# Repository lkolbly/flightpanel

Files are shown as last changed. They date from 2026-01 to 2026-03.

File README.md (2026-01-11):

DIY Flightpanel
===============

Welcome to my DIY flightpanel. There are three components to this project:

* Mechanical design
* PCB design
* Firmware

All three are custom-built for this project.

PCB
===

The PCB has support for up to the following inputs:

* 16x push buttons
* 14x double-throw switches
* 6x rotary encoders with push-buttons
* 10x potentiometers or hall-effect sensors

(note that Windows only supports up to 8 axes)

Mechanical
==========

The mechanical design is in FreeCAD, in the `flightpanel.FCStd` file. Within
that project look at the Assembly for a reference design with all included
components, including stand-ins for various knobs and switches.

The design is oriented around providing a standardized base, with swappable
control scheme panels. Each panel has a working area of 60mm wide by 100mm tall
- see BigPanelTemplate in the FreeCAD project for a template. Two panels may be
combined to create a "wide" 128mm by 100mm panel.

The panel should extend 3.5mm past the centers of the holes for optimum
mechanical support.

The core structure provides space for up to 6 panels - two on the front face,
two on the top face (with an approximately 30 degree slope), and one on each
side.

The core consists of the following parts:
- `StructureFront`
- `StructureTop`
- `StructureBase`
- `SidePanel`

The mounting on the back is two M6 holes spaced 40mm apart vertically. Mouse bites are provided for additional rigidity. The `Mount` part provides a reference design for a mount - as modelled, for mounting to a 35mm wide square tube.

Hardware required for assembly:
- Heat-set M3 threaded inserts, designed for a 4.5mm diameter hole with 5mm depth.
- 14 to 38x M3 by 8mm bolts (14 for structure assembly, up to 24 for mounting panels).
- 2x M6 by 20mm bolts with nuts.

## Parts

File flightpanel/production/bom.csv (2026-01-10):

Designator | Footprint | Quantity | Value | LCSC Part #
C1, C10, C12, C2, C20, C22, C27, C28, C29, C4, C6, C8 | 0603 | 12 | 0.01uF | C57112
C11, C14, C16, C9 | 0603 | 4 | 4.7uF | C19666
C13, C18, C23, C24, C25, C3, C5, C7 | 0603 | 8 | 0.1uF | C14663
D1, D2 | 0603 | 2 | LED | C2286
J1 | USB-B-TH_USB-B10-BRW | 1 | USB_B | C720549
J10, J9 | PinHeader_1x04_P2.54mm_Vertical | 2 | Conn_01x04
J11, J7, J8 | PinHeader_1x03_P2.54mm_Vertical | 3 | Conn_01x03_Pin
J12 | PinHeader_2x05_P1.27mm_Vertical | 1 | Conn_ARM_JTAG_SWD_10 | C239059
J13 | PinHeader_1x03_P2.54mm_Vertical | 1 | Conn_01x03_Pin | C146690
J14, J2, J3, J4, J5, J6 | PinSocket_1x05_P2.54mm_Vertical | 6 | Conn_01x05 | C50950
R1, R10, R11, R12, R13, R14, R15, R16, R17, R18, R19, R2, R20, R3, R4, R43, R46, R49, R5, R50, R51, R52, R6, R7, R8, R9 | 0603 | 26 | 10k | C25804
R21, R22, R41, R42 | 0603 | 4 | 3k | C4211
R44, R45 | 0603 | 2 | 1k | C21190
R47, R48 | 0603 | 2 | 100k | C25803
RV1, RV2, RV3, RV4, RV5, RV6, RV7, RV8 | PinSocket_1x03_P2.54mm_Vertical | 8 | 10k | C146690
SW1, SW10, SW11, SW12, SW13, SW14, SW15, SW16, SW2, SW27, SW28, SW29, SW3, SW4, SW5, SW6, SW7, SW8, SW9 | PinSocket_1x02_P2.54mm_Vertical | 19 | SW_Push | C49661
SW17, SW18, SW19, SW20, SW21, SW22, SW23, SW32, SW33, SW34, SW35, SW36, SW37, SW38 | PinSocket_1x03_P2.54mm_Vertical | 14 | SW_SPDT | C146690
SW24 | SW-SMD_L3.9-W3.0-P4.45 | 1 | NRST | C720477
SW25 | SW-SMD_L3.9-W3.0-P4.45 | 1 | CFG | C720477
SW26 | SW-SMD_L3.9-W3.0-P4.45 | 1 | BOOT | C720477
TP1, TP2, TP3, TP4, TP5, TP6, TP7 | TestPoint_Pad_D2.0mm | 7 | TestPoint
U1, U2, U5, U7 | WQFN-24-1EP_4x4mm_P0.5mm_EP2.45x2.45mm | 4 | TCA9555RTWR | C140277
U3 | LQFP-48_7x7mm_P0.5mm | 1 | STM32F072CBTx | C81720
U6 | SOT-23-5 | 1 | TPS76333 | C7100

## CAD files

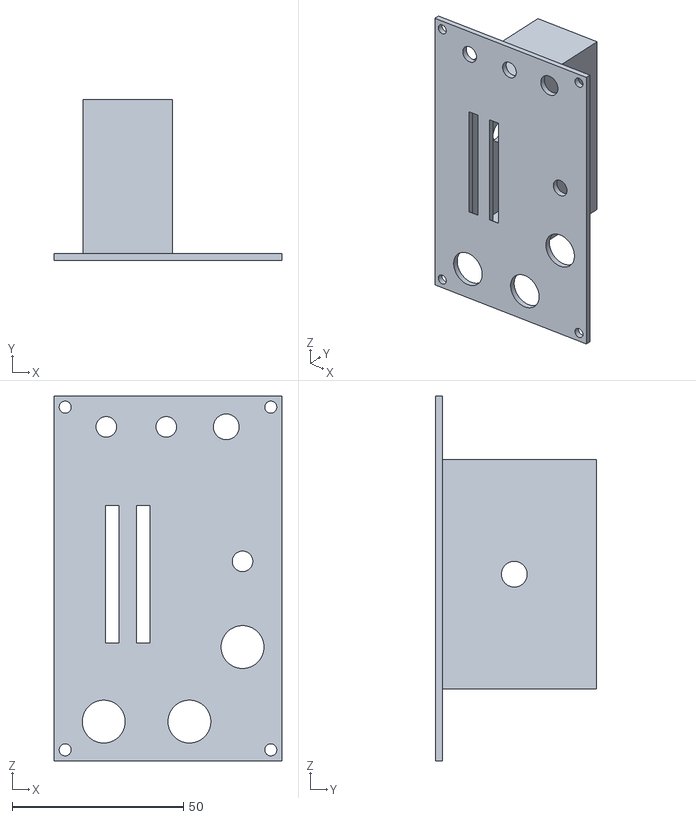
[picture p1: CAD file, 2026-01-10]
manufacturing/flightpanel-AssemblyFrontPlateModule001.stl
66.5 x 47.0 x 106.5

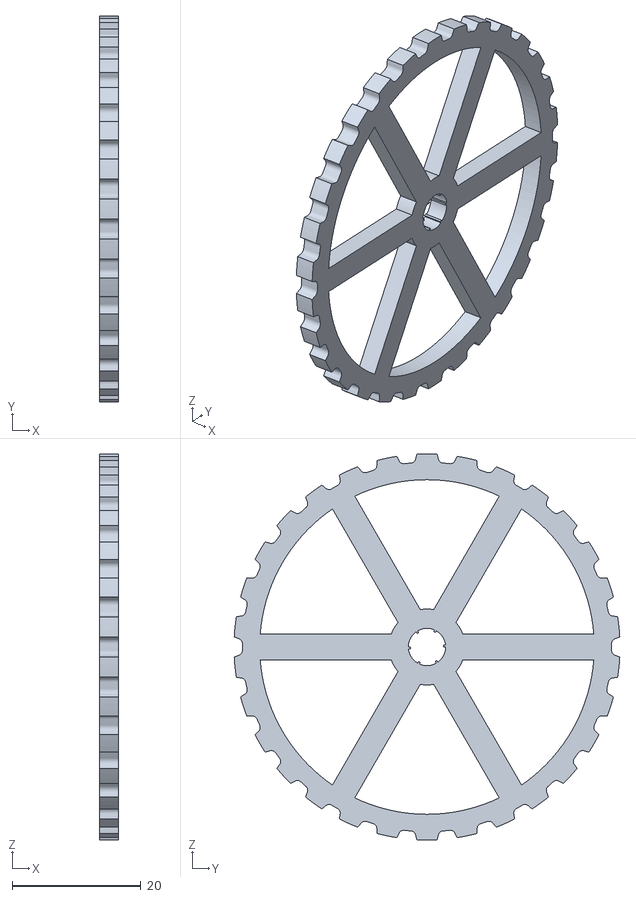
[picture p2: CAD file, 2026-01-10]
manufacturing/flightpanel-AssemblyWheel001.stl
3.00 x 59.9 x 60.0

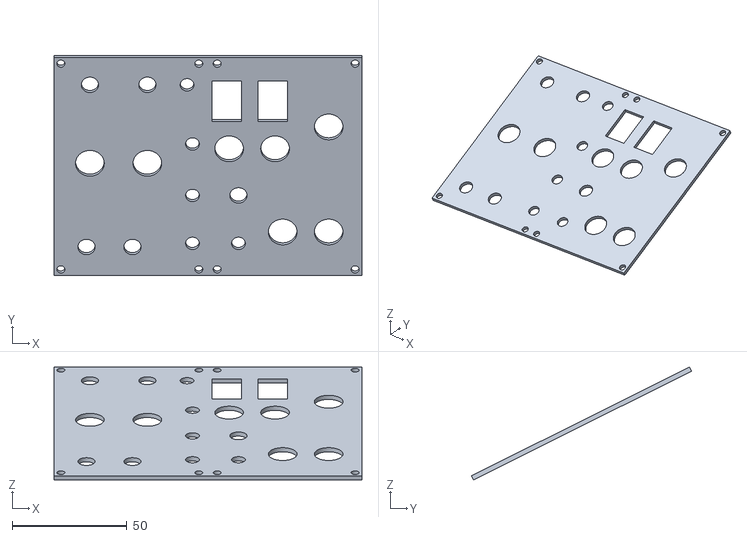
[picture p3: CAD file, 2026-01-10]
manufacturing/flightpanel-AssemblyBigTopPlateModule001.stl
134.0 x 95.8 x 49.1

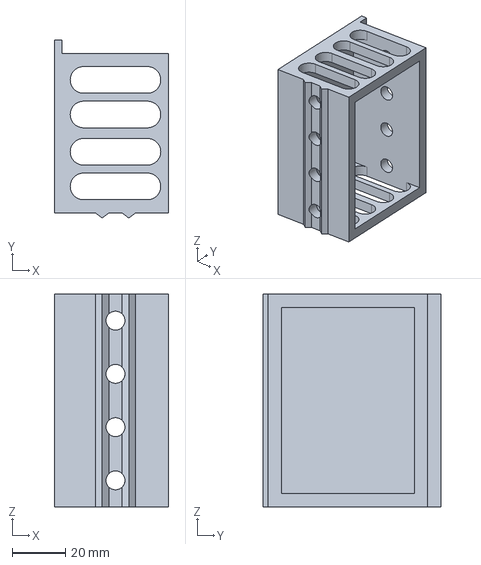
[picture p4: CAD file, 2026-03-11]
flightpanel.FCStd
43.0 x 66.9 x 80.0 mm

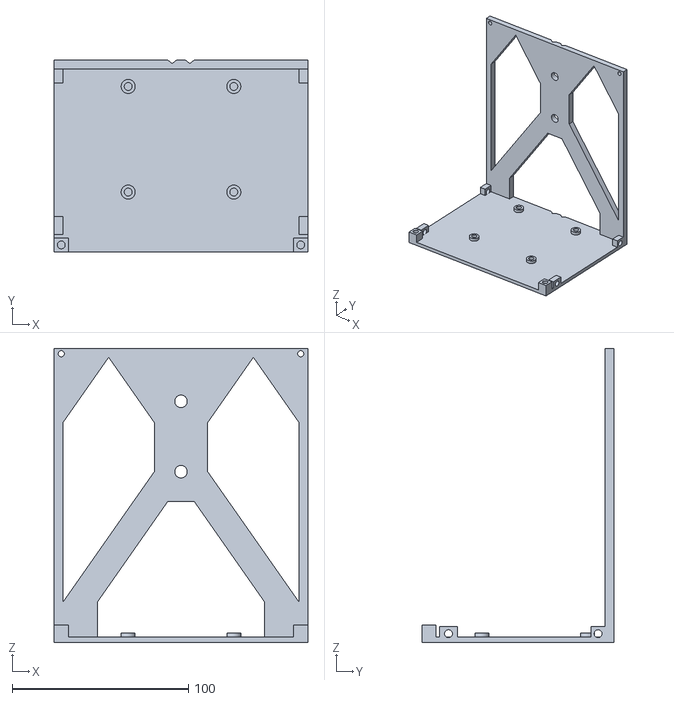
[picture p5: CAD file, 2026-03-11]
manufacturing/flightpanel-PartStructureBase.stl
144.0 x 109.0 x 167.0

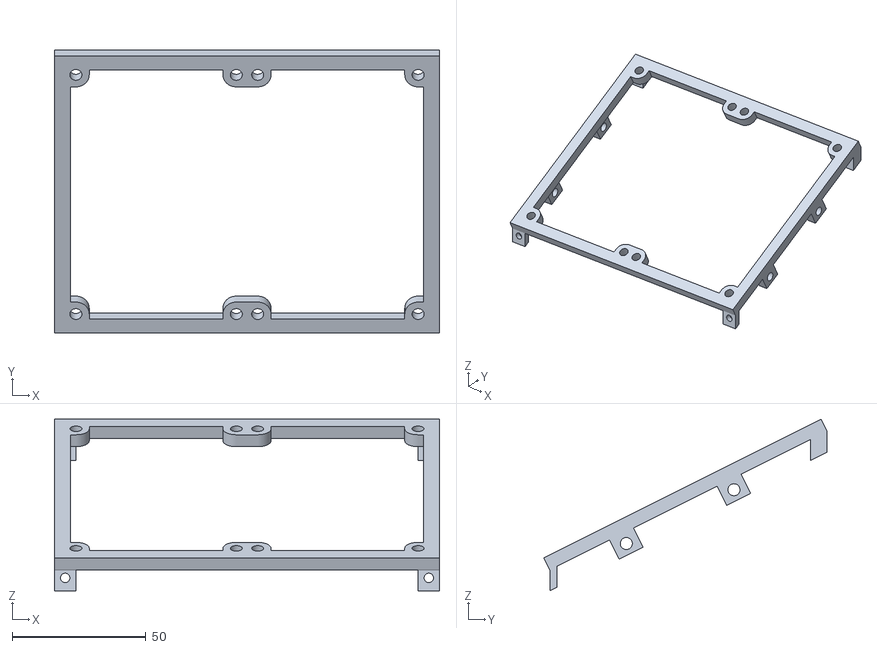
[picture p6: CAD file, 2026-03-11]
manufacturing/flightpanel-PartStructureTop.stl
144.0 x 106.0 x 64.2

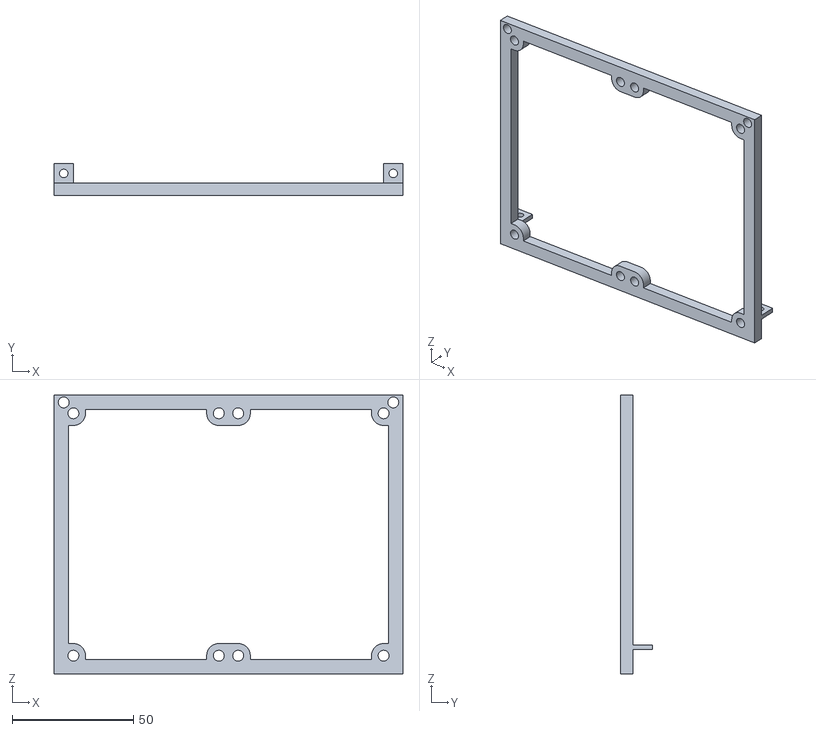
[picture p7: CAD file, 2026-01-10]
manufacturing/flightpanel-PartStructureFront.stl
144.0 x 13.0 x 115.0

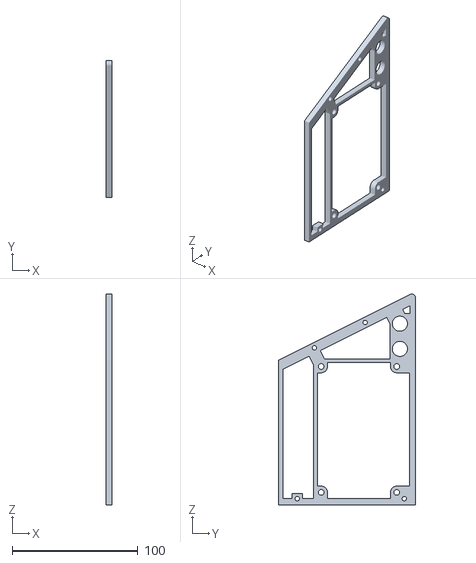
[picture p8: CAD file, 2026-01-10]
manufacturing/flightpanel-PartSidePanel.stl
5.00 x 109.0 x 167.6

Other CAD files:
manufacturing/flightpanel-PartMount.stl

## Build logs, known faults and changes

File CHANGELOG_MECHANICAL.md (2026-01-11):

v1.1
====
- Increased panel width to 3mm (to remove 6mm bolts as dependency)
- Fixed PCB mount hole depth
- Made StructureTop overlap with panels for edge mechanical support
- TODO: Re-layout front panel module to account for PCB spacing and DFM for trim wheels

v1.0
====
- Initial revision

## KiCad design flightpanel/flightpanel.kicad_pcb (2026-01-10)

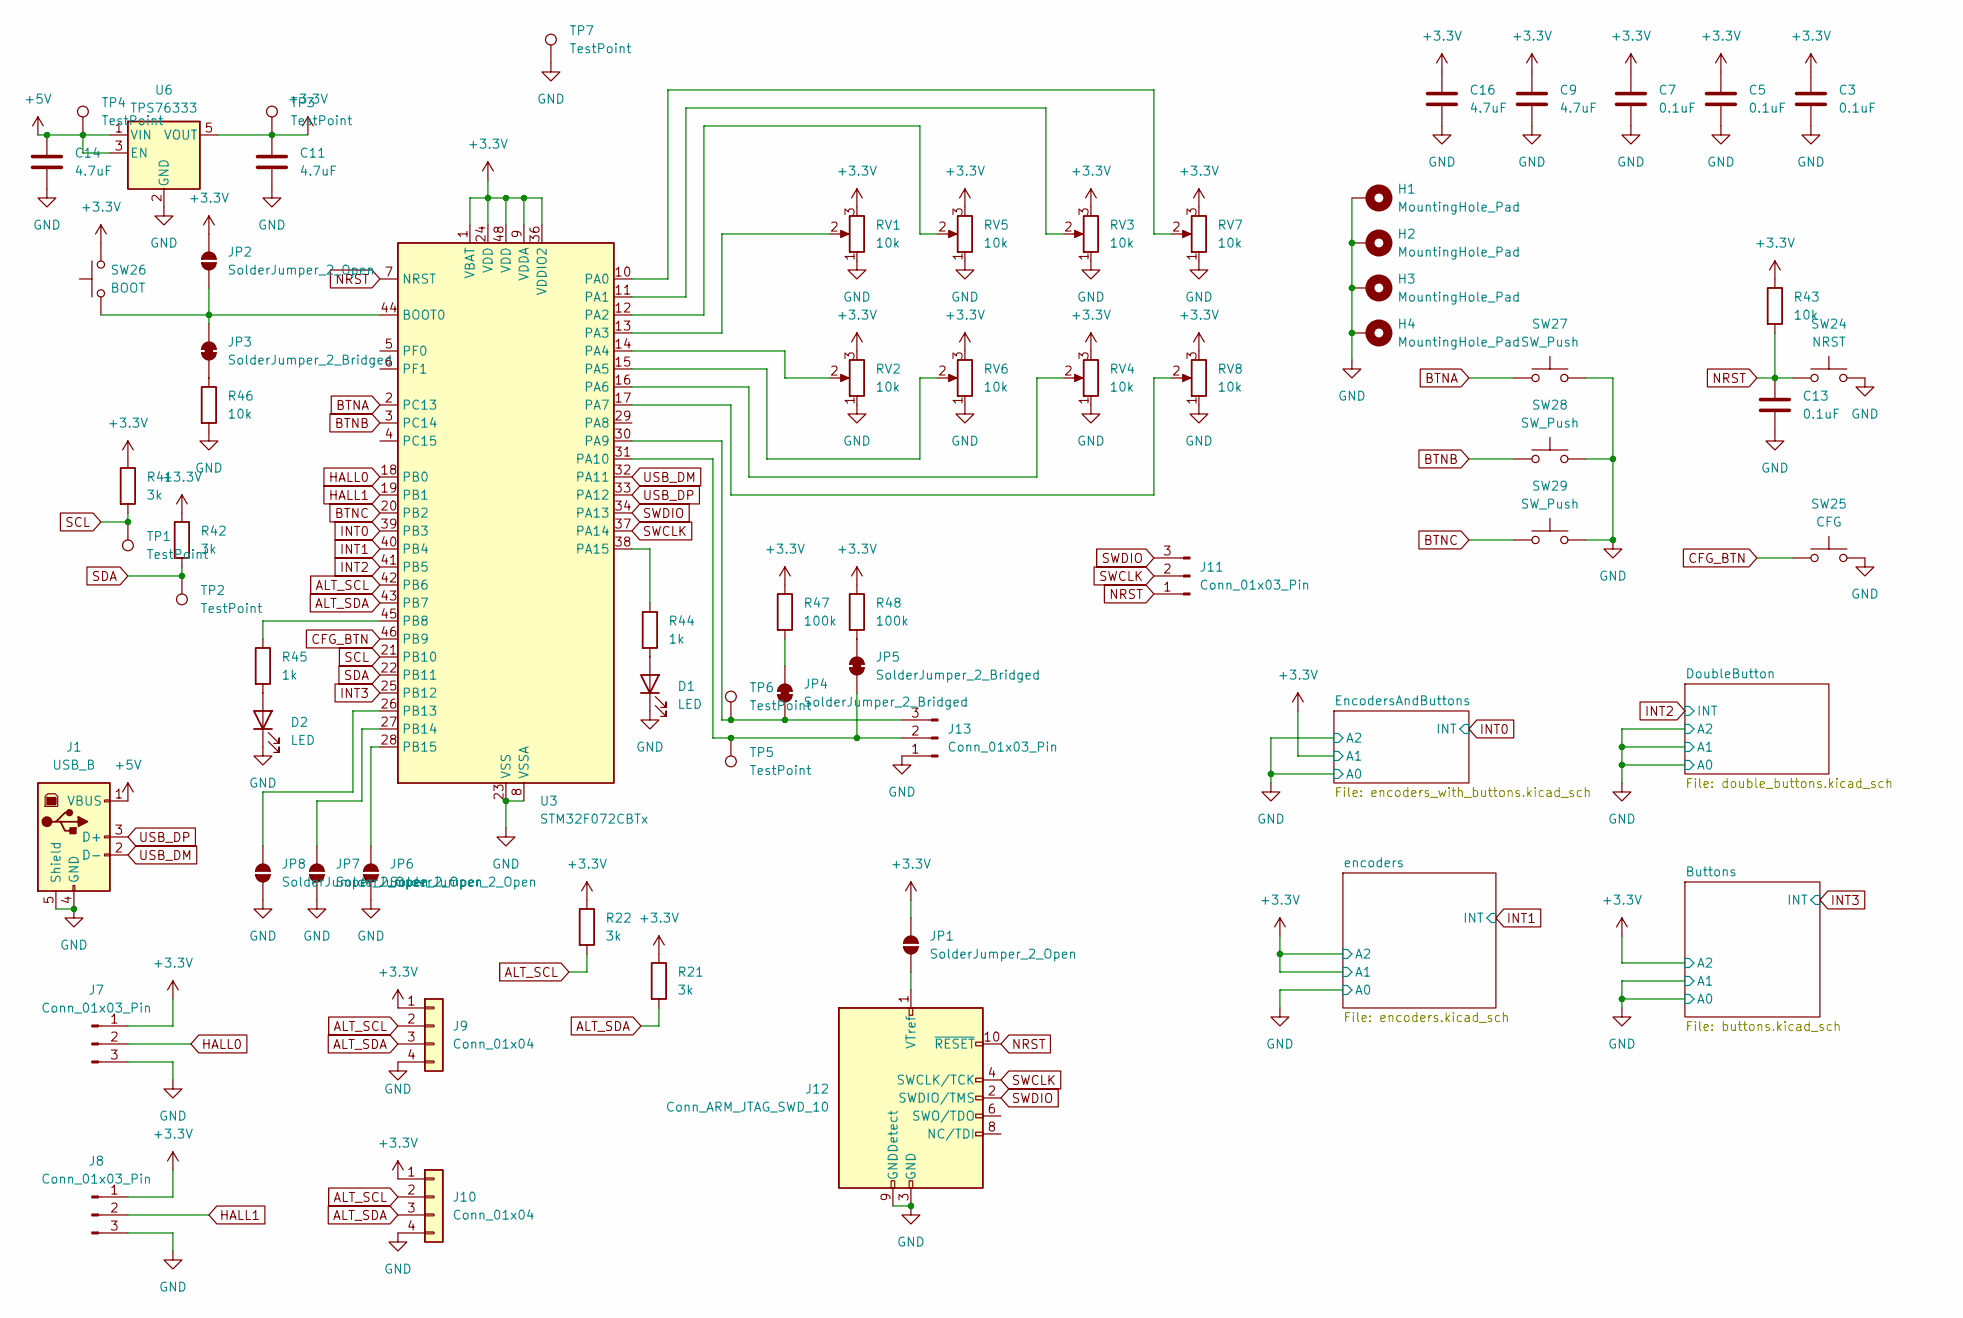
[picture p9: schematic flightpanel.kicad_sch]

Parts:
C3, C5, C7, C13: 0.1uF; C_0603_1608Metric; LCSC Part Number C14663
C9, C11, C14, C16: 4.7uF; C_0603_1608Metric; LCSC Part Number C19666
D1, D2: LED; LED_0603_1608Metric; LCSC Part Number C2286
H1, H2, H3, H4: MountingHole_Pad; MountingHole_3.2mm_M3_Pad
J1: USB_B; USB-B-TH_USB-B10-BRW; LCSC Part Number C720549
J7, J8, J11: Conn_01x03_Pin; PinHeader_1x03_P2.54mm_Vertical
J9, J10: Conn_01x04; PinHeader_1x04_P2.54mm_Vertical
J12: Conn_ARM_JTAG_SWD_10; PinHeader_2x05_P1.27mm_Vertical; LCSC Part Number C239059
J13: Conn_01x03_Pin; PinHeader_1x03_P2.54mm_Vertical; LCSC Part Number C146690
JP1, JP2, JP6, JP7, JP8: SolderJumper_2_Open; SolderJumper-2_P1.3mm_Open_RoundedPad1.0x1.5mm
JP3, JP4, JP5: SolderJumper_2_Bridged; SolderJumper-2_P1.3mm_Bridged_RoundedPad1.0x1.5mm
R21, R22, R41, R42: 3k; R_0603_1608Metric; LCSC Part Number C4211
R43, R46: 10k; R_0603_1608Metric; LCSC Part Number C25804
R44, R45: 1k; R_0603_1608Metric; LCSC Part Number C21190
R47, R48: 100k; R_0603_1608Metric; LCSC Part Number C25803
RV1, RV2, RV3, RV4, RV5, RV6, RV7, RV8: 10k; PinSocket_1x03_P2.54mm_Vertical; LCSC Part Number C146690
SW24: NRST; SW-SMD_L3.9-W3.0-P4.45; LCSC Part Number C720477
SW25: CFG; SW-SMD_L3.9-W3.0-P4.45; LCSC Part Number C720477
SW26: BOOT; SW-SMD_L3.9-W3.0-P4.45; LCSC Part Number C720477
SW27, SW28, SW29: SW_Push; PinSocket_1x02_P2.54mm_Vertical; LCSC Part Number C49661
TP1, TP2, TP3, TP4, TP5, TP6, TP7: TestPoint; TestPoint_Pad_D2.0mm
U3: STM32F072CBTx; LQFP-48_7x7mm_P0.5mm; LCSC Part Number C81720
U6: TPS76333; SOT-23-5; LCSC Part Number C7100

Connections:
+3.3V: C3.1, C5.1, C7.1, C9.1, C11.1, C16.1, J7.1, J8.1, J9.1, J10.1, JP1.2 (B), JP2.2 (B), R21.1, R22.1, R41.1, R42.1, R43.1, R47.1, R48.1, RV1.3, RV2.3, RV3.3, RV4.3, RV5.3, RV6.3, RV7.3, RV8.3, SW26.2, TP3.1, U3.1 (VBAT), U3.9 (VDDA), U3.24 (VDD), U3.36 (VDDIO2), U3.48 (VDD), U6.5 (VOUT); also elsewhere on the board
+5V: C14.1, J1.1 (VBUS), TP4.1, U6.1 (VIN), U6.3 (EN)
ALT_SCL: J9.2, J10.2, R22.2, U3.42 (PB6)
ALT_SDA: J9.3, J10.3, R21.2, U3.43 (PB7)
BTNA: SW27.1, U3.2 (PC13)
BTNB: SW28.1, U3.3 (PC14)
BTNC: SW29.1, U3.20 (PB2)
CFG_BTN: SW25.1, U3.46 (PB9)
GND: C3.2, C5.2, C7.2, C9.2, C11.2, C13.2, C14.2, C16.2, D1.1 (K), D2.1 (K), H1.1, H2.1, H3.1, H4.1, J1.4 (GND), J1.5 (Shield), J7.3, J8.3, J9.4, J10.4, J12.3 (GND), J12.5 (GND), J12.9 (GNDDetect), J13.1, JP6.1 (A), JP7.1 (A), JP8.1 (A), R46.2, RV1.1, RV2.1, RV3.1, RV4.1, RV5.1, RV6.1, RV7.1, RV8.1, SW24.2, SW25.2, SW27.2, SW28.2, SW29.2, TP7.1, U3.8 (VSSA), U3.23 (VSS), U3.35 (VSS), U3.47 (VSS), U6.2 (GND); also elsewhere on the board
HALL0: J7.2, U3.18 (PB0)
HALL1: J8.2, U3.19 (PB1)
INT0: U3.39 (PB3); also elsewhere on the board
INT1: U3.40 (PB4); also elsewhere on the board
INT2: U3.41 (PB5); also elsewhere on the board
INT3: U3.25 (PB12); also elsewhere on the board
NRST: C13.1, J11.1, J12.10 (~RESET), R43.2, SW24.1, U3.7 (NRST)
unnamed: D1.2 (A), R44.2
unnamed: D2.2 (A), R45.2
unnamed: J12.1 (VTref), JP1.1 (A)
unnamed: J13.2, JP5.1 (A), TP5.1, U3.31 (PA10)
unnamed: J13.3, JP4.1 (A), TP6.1, U3.30 (PA9)
unnamed: JP2.1 (A), JP3.2 (B), SW26.1, U3.44 (BOOT0)
unnamed: JP3.1 (A), R46.1
unnamed: JP4.2 (B), R47.2
unnamed: JP5.2 (B), R48.2
unnamed: JP6.2 (B), U3.28 (PB15)
unnamed: JP7.2 (B), U3.27 (PB14)
unnamed: JP8.2 (B), U3.26 (PB13)
unnamed: RV7.2, U3.10 (PA0)
unnamed: RV3.2, U3.11 (PA1)
unnamed: RV5.2, U3.12 (PA2)
unnamed: RV1.2, U3.13 (PA3)
unnamed: RV2.2, U3.14 (PA4)
unnamed: RV6.2, U3.15 (PA5)
unnamed: RV4.2, U3.16 (PA6)
unnamed: RV8.2, U3.17 (PA7)
unnamed: R44.1, U3.38 (PA15)
unnamed: R45.1, U3.45 (PB8)
SCL: R41.2, TP1.1, U3.21 (PB10); also elsewhere on the board
SDA: R42.2, TP2.1, U3.22 (PB11); also elsewhere on the board
SWCLK: J11.2, J12.4 (SWCLK/TCK), U3.37 (PA14)
SWDIO: J11.3, J12.2 (SWDIO/TMS), U3.34 (PA13)
USB_DM: J1.2 (D-), U3.32 (PA11)
USB_DP: J1.3 (D+), U3.33 (PA12)

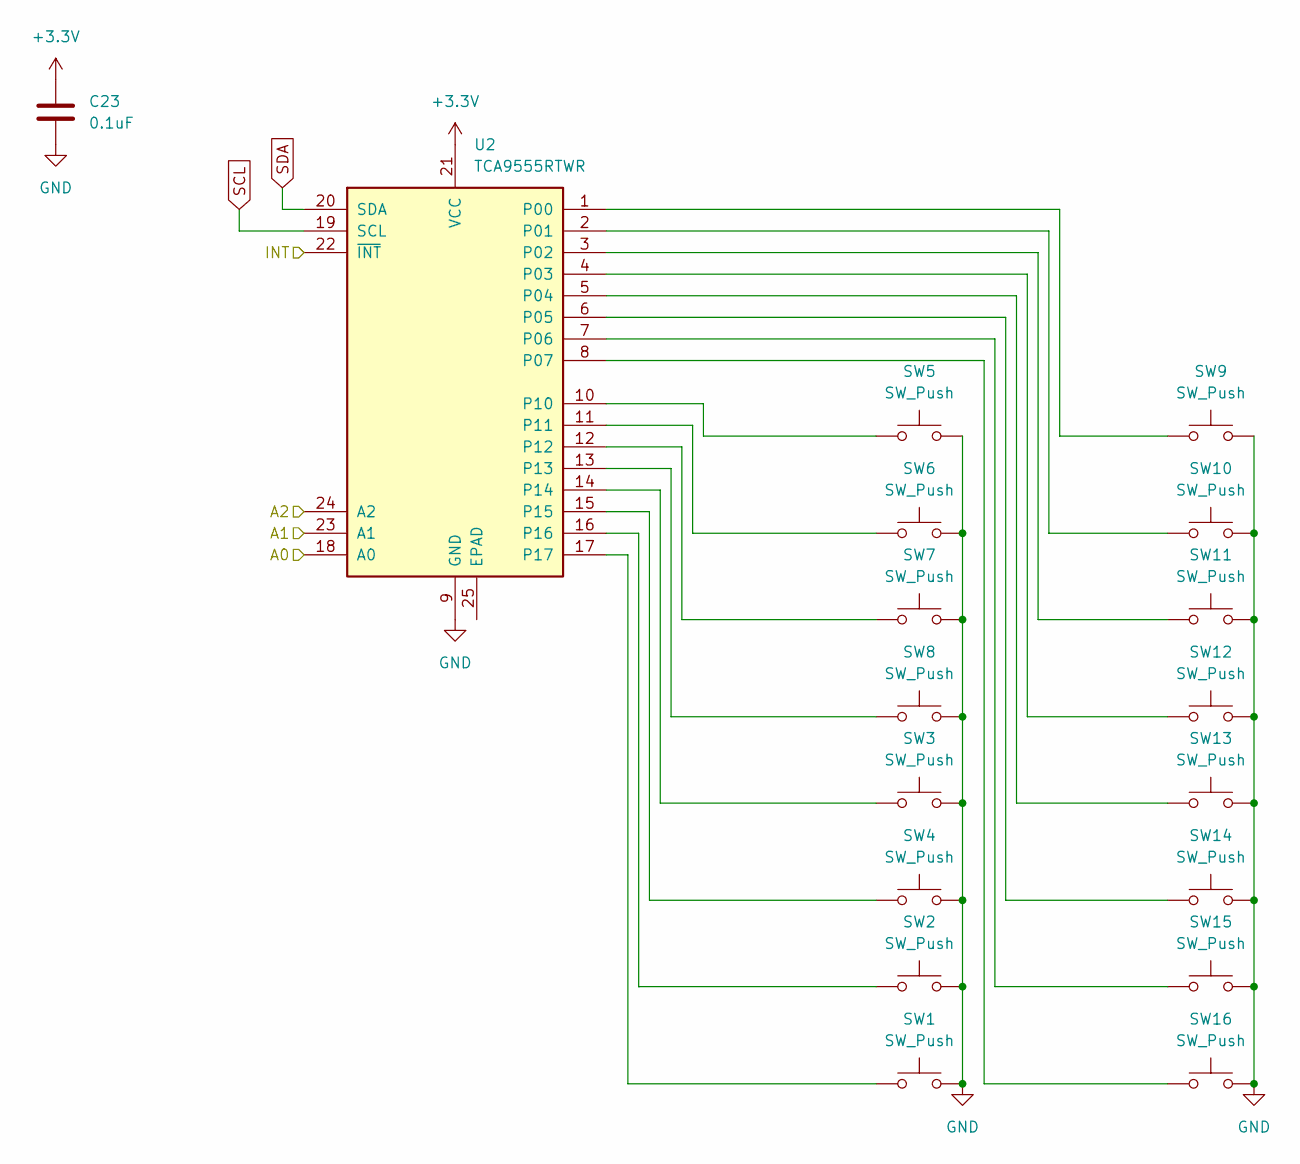
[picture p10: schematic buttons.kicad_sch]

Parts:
C23: 0.1uF; C_0603_1608Metric; LCSC Part Number C14663
SW1, SW2, SW3, SW4, SW5, SW6, SW7, SW8, SW9, SW10, SW11, SW12, SW13, SW14, SW15, SW16: SW_Push; PinSocket_1x02_P2.54mm_Vertical; LCSC Part Number C49661
U2: TCA9555RTWR; WQFN-24-1EP_4x4mm_P0.5mm_EP2.45x2.45mm; LCSC Part Number C140277

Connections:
+3.3V: C23.1, U2.21 (VCC), U2.24 (A2); also elsewhere on the board
GND: C23.2, SW1.2, SW2.2, SW3.2, SW4.2, SW5.2, SW6.2, SW7.2, SW8.2, SW9.2, SW10.2, SW11.2, SW12.2, SW13.2, SW14.2, SW15.2, SW16.2, U2.9 (GND), U2.18 (A0), U2.23 (A1); also elsewhere on the board
INT3: U2.22 (~INT); also elsewhere on the board
unnamed: SW9.1, U2.1 (P00)
unnamed: SW10.1, U2.2 (P01)
unnamed: SW11.1, U2.3 (P02)
unnamed: SW12.1, U2.4 (P03)
unnamed: SW13.1, U2.5 (P04)
unnamed: SW14.1, U2.6 (P05)
unnamed: SW15.1, U2.7 (P06)
unnamed: SW16.1, U2.8 (P07)
unnamed: SW5.1, U2.10
unnamed: SW6.1, U2.11
unnamed: SW7.1, U2.12
unnamed: SW8.1, U2.13
unnamed: SW3.1, U2.14
unnamed: SW4.1, U2.15
unnamed: SW2.1, U2.16
unnamed: SW1.1, U2.17
SCL: U2.19 (SCL); also elsewhere on the board
SDA: U2.20 (SDA); also elsewhere on the board

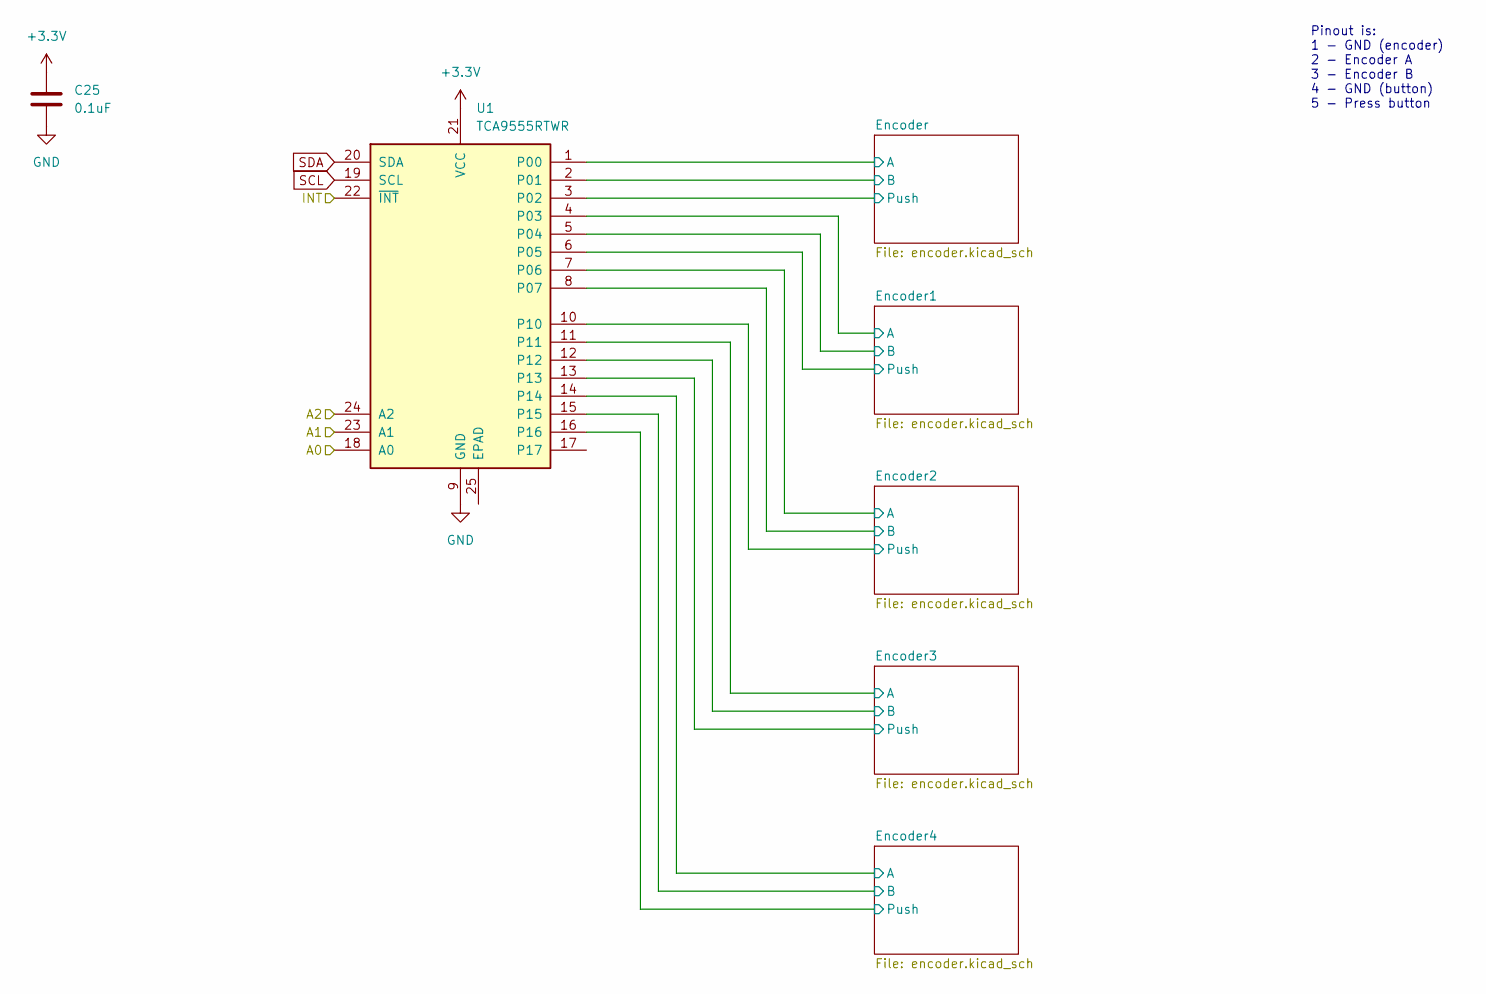
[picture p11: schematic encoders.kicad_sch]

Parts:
C25: 0.1uF; C_0603_1608Metric; LCSC Part Number C14663
U1: TCA9555RTWR; WQFN-24-1EP_4x4mm_P0.5mm_EP2.45x2.45mm; LCSC Part Number C140277

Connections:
+3.3V: C25.1, U1.21 (VCC), U1.23 (A1), U1.24 (A2); also elsewhere on the board
/encoders/Encoder1/A: U1.4 (P03); also elsewhere on the board
/encoders/Encoder1/B: U1.5 (P04); also elsewhere on the board
/encoders/Encoder1/Push: U1.6 (P05); also elsewhere on the board
/encoders/Encoder2/A: U1.7 (P06); also elsewhere on the board
/encoders/Encoder2/B: U1.8 (P07); also elsewhere on the board
/encoders/Encoder2/Push: U1.10; also elsewhere on the board
/encoders/Encoder3/A: U1.11; also elsewhere on the board
/encoders/Encoder3/B: U1.12; also elsewhere on the board
/encoders/Encoder3/Push: U1.13; also elsewhere on the board
/encoders/Encoder4/A: U1.14; also elsewhere on the board
/encoders/Encoder4/B: U1.15; also elsewhere on the board
/encoders/Encoder4/Push: U1.16; also elsewhere on the board
/encoders/Encoder/A: U1.1 (P00); also elsewhere on the board
/encoders/Encoder/B: U1.2 (P01); also elsewhere on the board
/encoders/Encoder/Push: U1.3 (P02); also elsewhere on the board
GND: C25.2, U1.9 (GND), U1.18 (A0); also elsewhere on the board
INT1: U1.22 (~INT); also elsewhere on the board
SCL: U1.19 (SCL); also elsewhere on the board
SDA: U1.20 (SDA); also elsewhere on the board

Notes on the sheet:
Pinout is: 1 - GND (encoder) 2 - Encoder A 3 - Encoder B 4 - GND (button) 5 - Press button

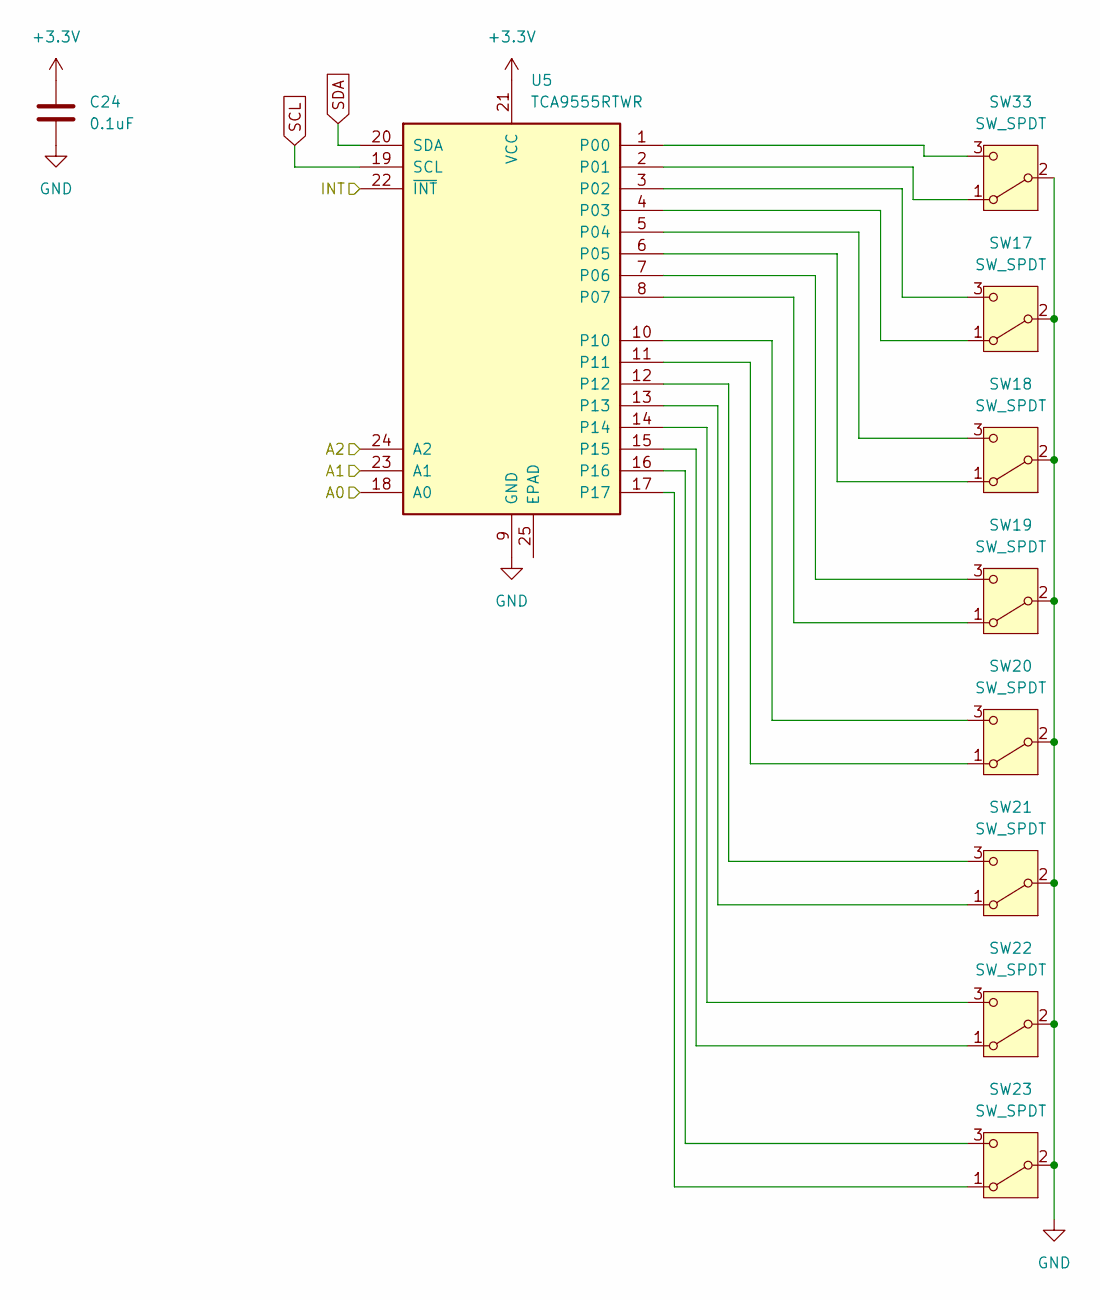
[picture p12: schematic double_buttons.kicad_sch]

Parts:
C24: 0.1uF; C_0603_1608Metric; LCSC Part Number C14663
SW17, SW18, SW19, SW20, SW21, SW22, SW23, SW33: SW_SPDT; PinSocket_1x03_P2.54mm_Vertical; LCSC Part Number C146690
U5: TCA9555RTWR; WQFN-24-1EP_4x4mm_P0.5mm_EP2.45x2.45mm; LCSC Part Number C140277

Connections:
+3.3V: C24.1, U5.21 (VCC); also elsewhere on the board
GND: C24.2, SW17.2 (B), SW18.2 (B), SW19.2 (B), SW20.2 (B), SW21.2 (B), SW22.2 (B), SW23.2 (B), SW33.2 (B), U5.9 (GND), U5.18 (A0), U5.23 (A1), U5.24 (A2); also elsewhere on the board
INT2: U5.22 (~INT); also elsewhere on the board
unnamed: SW17.1 (A), U5.4 (P03)
unnamed: SW17.3 (C), U5.3 (P02)
unnamed: SW18.1 (A), U5.6 (P05)
unnamed: SW18.3 (C), U5.5 (P04)
unnamed: SW19.1 (A), U5.8 (P07)
unnamed: SW19.3 (C), U5.7 (P06)
unnamed: SW20.1 (A), U5.11
unnamed: SW20.3 (C), U5.10
unnamed: SW21.1 (A), U5.13
unnamed: SW21.3 (C), U5.12
unnamed: SW22.1 (A), U5.15
unnamed: SW22.3 (C), U5.14
unnamed: SW23.1 (A), U5.17
unnamed: SW23.3 (C), U5.16
unnamed: SW33.1 (A), U5.2 (P01)
unnamed: SW33.3 (C), U5.1 (P00)
SCL: U5.19 (SCL); also elsewhere on the board
SDA: U5.20 (SDA); also elsewhere on the board

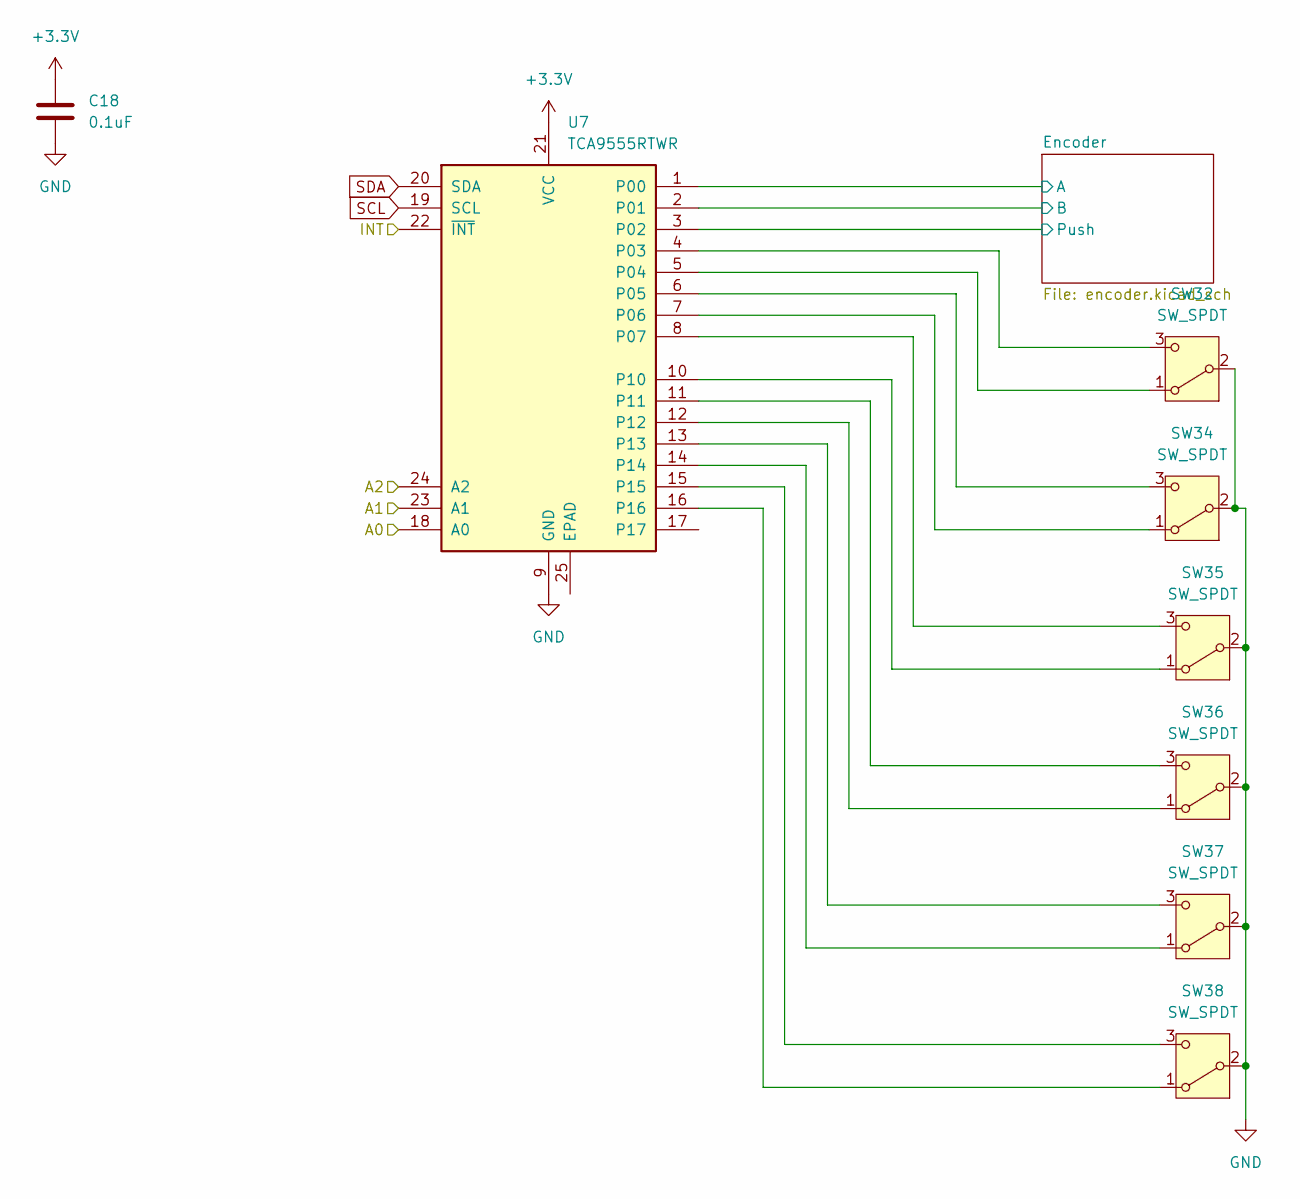
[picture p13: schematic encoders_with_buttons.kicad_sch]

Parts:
C18: 0.1uF; C_0603_1608Metric; LCSC Part Number C14663
SW32, SW34, SW35, SW36, SW37, SW38: SW_SPDT; PinSocket_1x03_P2.54mm_Vertical; LCSC Part Number C146690
U7: TCA9555RTWR; WQFN-24-1EP_4x4mm_P0.5mm_EP2.45x2.45mm; LCSC Part Number C140277

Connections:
+3.3V: C18.1, U7.21 (VCC), U7.23 (A1); also elsewhere on the board
/EncodersAndButtons/Encoder/A: U7.1 (P00); also elsewhere on the board
/EncodersAndButtons/Encoder/B: U7.2 (P01); also elsewhere on the board
/EncodersAndButtons/Encoder/Push: U7.3 (P02); also elsewhere on the board
GND: C18.2, SW32.2 (B), SW34.2 (B), SW35.2 (B), SW36.2 (B), SW37.2 (B), SW38.2 (B), U7.9 (GND), U7.18 (A0), U7.24 (A2); also elsewhere on the board
INT0: U7.22 (~INT); also elsewhere on the board
unnamed: SW32.1 (A), U7.5 (P04)
unnamed: SW32.3 (C), U7.4 (P03)
unnamed: SW34.1 (A), U7.7 (P06)
unnamed: SW34.3 (C), U7.6 (P05)
unnamed: SW35.1 (A), U7.10
unnamed: SW35.3 (C), U7.8 (P07)
unnamed: SW36.1 (A), U7.12
unnamed: SW36.3 (C), U7.11
unnamed: SW37.1 (A), U7.14
unnamed: SW37.3 (C), U7.13
unnamed: SW38.1 (A), U7.16
unnamed: SW38.3 (C), U7.15
SCL: U7.19 (SCL); also elsewhere on the board
SDA: U7.20 (SDA); also elsewhere on the board

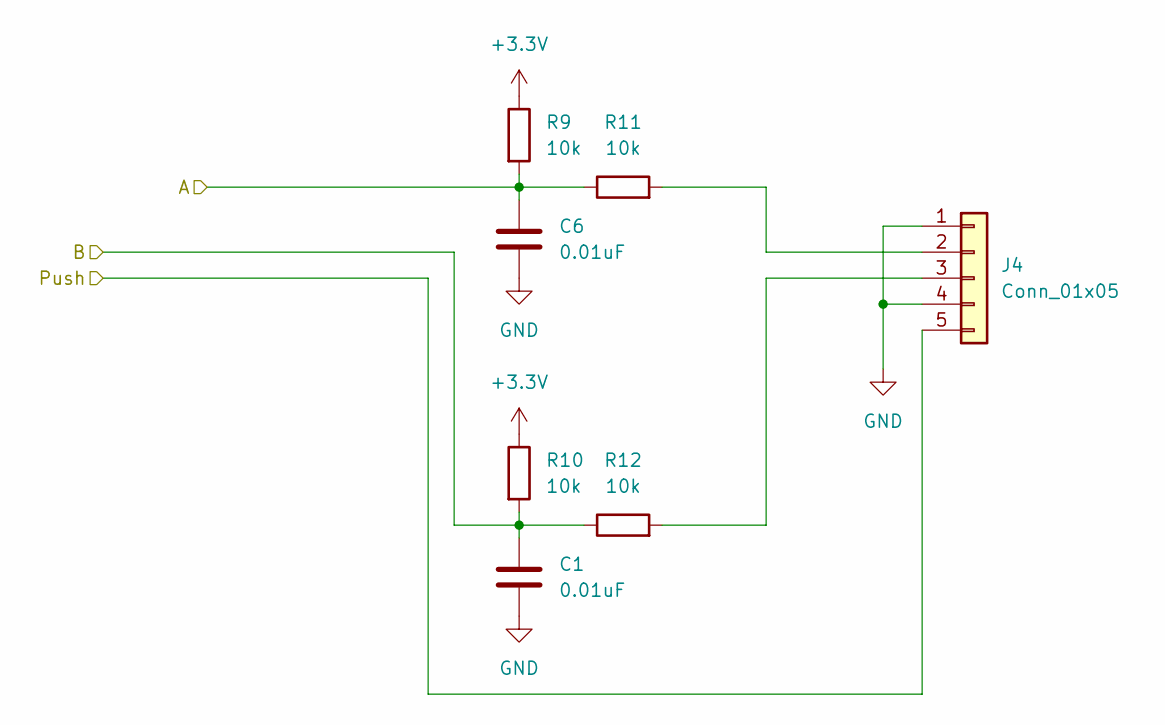
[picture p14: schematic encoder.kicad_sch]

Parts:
C1, C6: 0.01uF; C_0603_1608Metric; LCSC Part Number C57112
J4: Conn_01x05; PinSocket_1x05_P2.54mm_Vertical; LCSC Part Number C50950
R9, R10, R11, R12: 10k; R_0603_1608Metric; LCSC Part Number C25804

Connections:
+3.3V: R9.1, R10.1; also elsewhere on the board
/encoders/Encoder/A: C6.1, R9.2, R11.1; also elsewhere on the board
/encoders/Encoder/B: C1.1, R10.2, R12.1; also elsewhere on the board
/encoders/Encoder/Push: J4.5; also elsewhere on the board
GND: C1.2, C6.2, J4.1, J4.4; also elsewhere on the board
unnamed: J4.2, R11.2
unnamed: J4.3, R12.2

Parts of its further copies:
C2, C4, C8, C10, C12, C20, C22, C27, C28, C29: 0.01uF; C_0603_1608Metric; LCSC Part Number C57112
J2, J3, J5, J6, J14: Conn_01x05; PinSocket_1x05_P2.54mm_Vertical; LCSC Part Number C50950
R1, R2, R3, R4, R5, R6, R7, R8, R13, R14, R15, R16, R17, R18, R19, R20, R49, R50, R51, R52: 10k; R_0603_1608Metric; LCSC Part Number C25804

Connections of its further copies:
+3.3V: R1.1, R2.1, R5.1, R6.1, R13.1, R14.1, R17.1, R18.1, R49.1, R50.1; also elsewhere on the board
/EncodersAndButtons/Encoder/A: C20.1, R49.2, R51.1; also elsewhere on the board
/EncodersAndButtons/Encoder/B: C22.1, R50.2, R52.1; also elsewhere on the board
/EncodersAndButtons/Encoder/Push: J14.5; also elsewhere on the board
/encoders/Encoder1/A: C2.1, R1.2, R3.1; also elsewhere on the board
/encoders/Encoder1/B: C12.1, R2.2, R4.1; also elsewhere on the board
/encoders/Encoder1/Push: J2.5; also elsewhere on the board
/encoders/Encoder2/A: C4.1, R5.2, R7.1; also elsewhere on the board
/encoders/Encoder2/B: C27.1, R6.2, R8.1; also elsewhere on the board
/encoders/Encoder2/Push: J3.5; also elsewhere on the board
/encoders/Encoder3/A: C8.1, R13.2, R15.1; also elsewhere on the board
/encoders/Encoder3/B: C28.1, R14.2, R16.1; also elsewhere on the board
/encoders/Encoder3/Push: J5.5; also elsewhere on the board
/encoders/Encoder4/A: C10.1, R17.2, R19.1; also elsewhere on the board
/encoders/Encoder4/B: C29.1, R18.2, R20.1; also elsewhere on the board
/encoders/Encoder4/Push: J6.5; also elsewhere on the board
GND: C2.2, C4.2, C8.2, C10.2, C12.2, C20.2, C22.2, C27.2, C28.2, C29.2, J2.1, J2.4, J3.1, J3.4, J5.1, J5.4, J6.1, J6.4, J14.1, J14.4; also elsewhere on the board
unnamed: J2.2, R3.2
unnamed: J2.3, R4.2
unnamed: J3.2, R7.2
unnamed: J3.3, R8.2
unnamed: J5.2, R15.2
unnamed: J5.3, R16.2
unnamed: J6.2, R19.2
unnamed: J6.3, R20.2
unnamed: J14.2, R51.2
unnamed: J14.3, R52.2

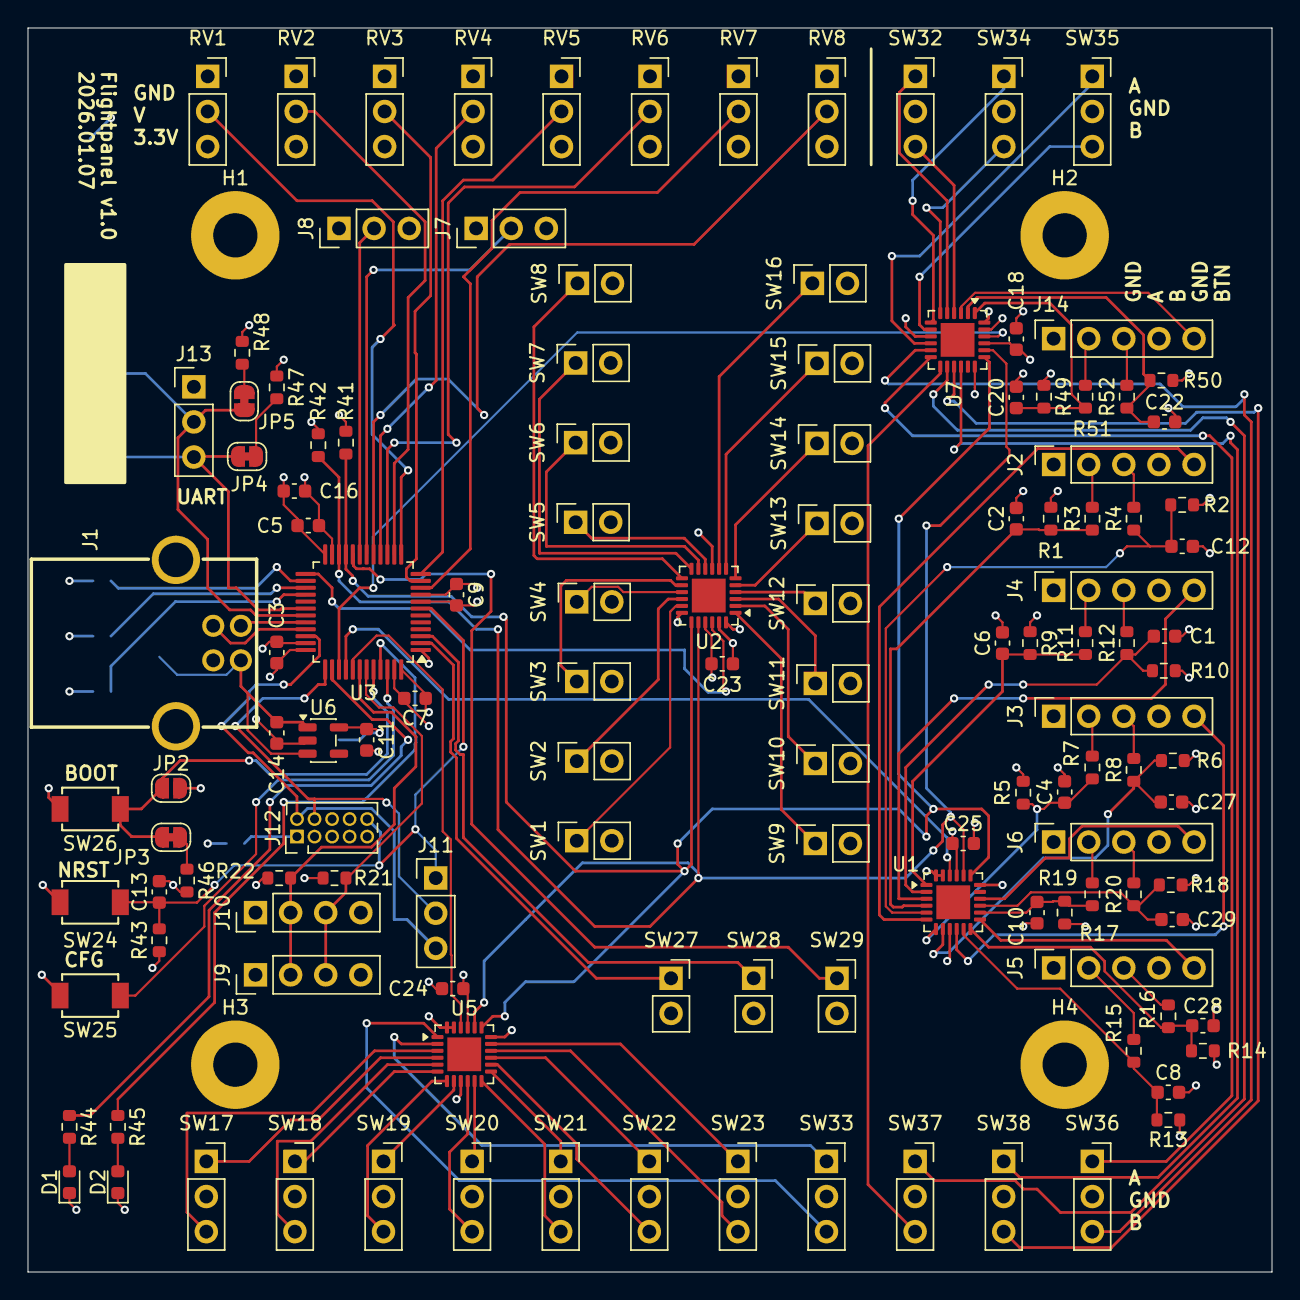
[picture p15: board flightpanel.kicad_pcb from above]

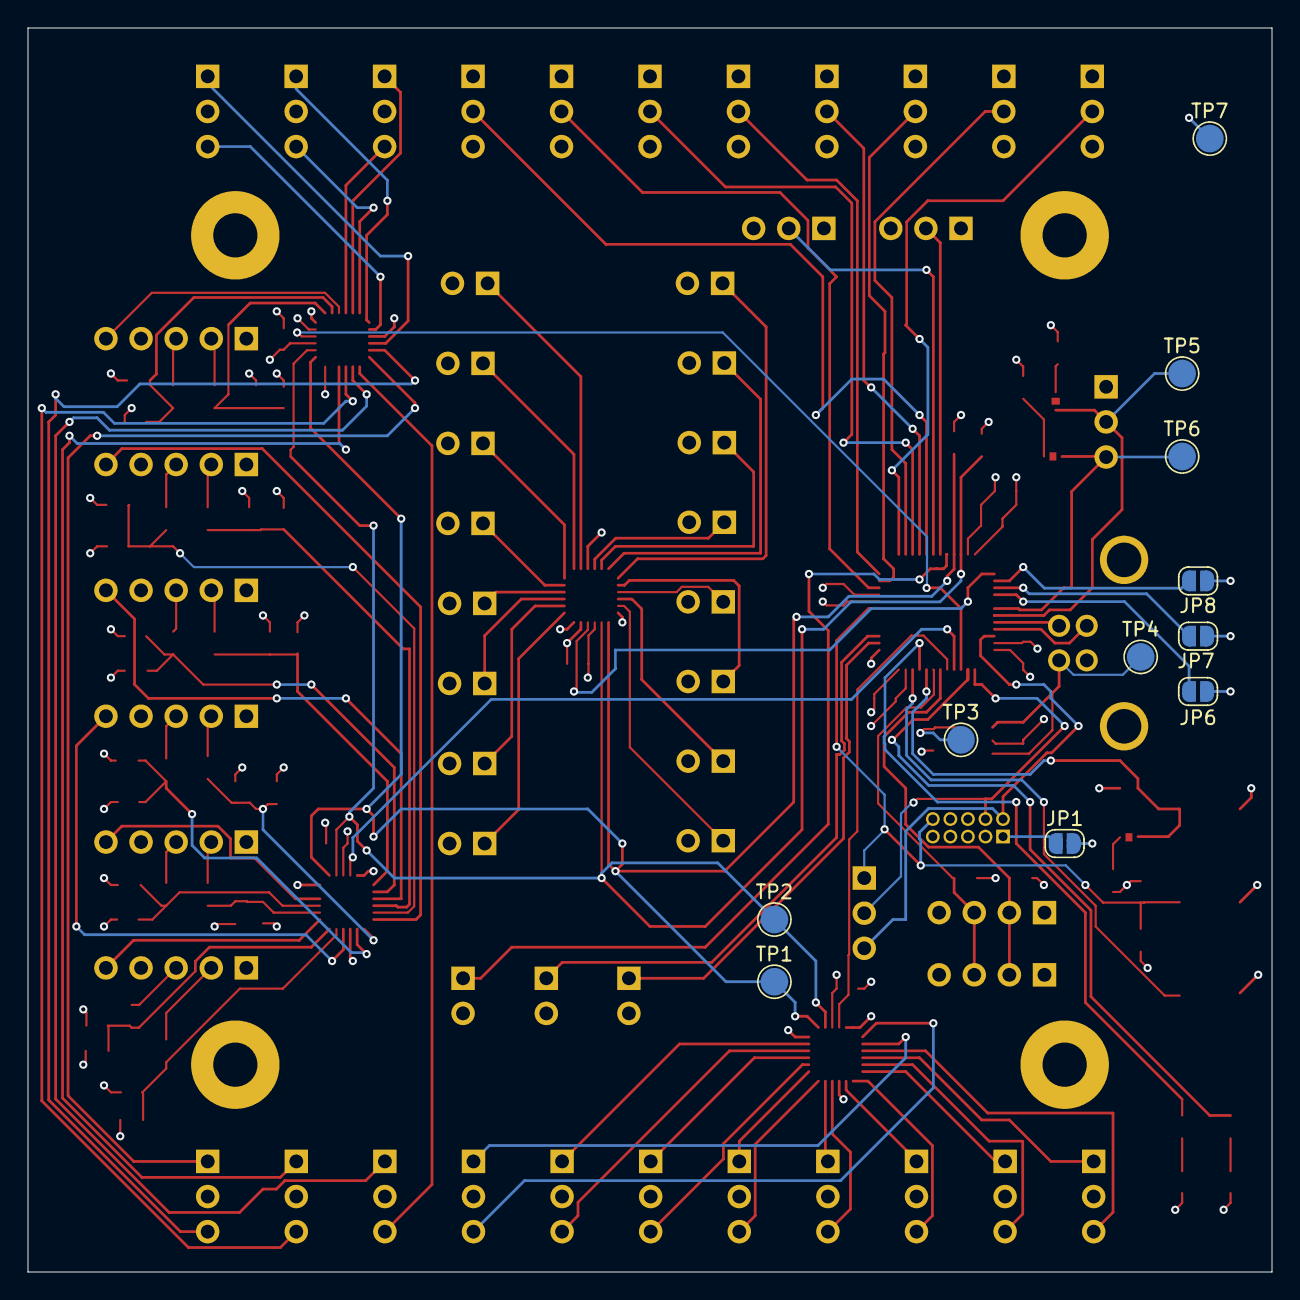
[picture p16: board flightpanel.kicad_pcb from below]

Board: 4 copper layers, 90.0 x 90.0 mm, 143 parts (11 on the bottom side), 118 nets.

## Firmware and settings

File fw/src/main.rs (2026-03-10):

#![no_std]
#![no_main]
#![feature(ascii_char)]
#![feature(sync_unsafe_cell)]
#![feature(int_lowest_highest_one)]

mod alloc;
mod fmt;
mod log;
mod trace;

use core::{
    cell::UnsafeCell,
    fmt::Write,
    hint::black_box,
    ops::{Deref, DerefMut},
    panic::PanicInfo,
    sync::atomic::AtomicUsize,
};

use embassy_embedded_hal::shared_bus::asynch::i2c::I2cDevice;
use embassy_sync::{
    blocking_mutex::{
        ThreadModeMutex,
        raw::{NoopRawMutex, RawMutex, ThreadModeRawMutex},
    },
    channel::{Channel, Sender},
    mutex::Mutex,
    once_lock::OnceLock,
};
use embassy_usb::{
    Builder,
    class::{
        cdc_acm::{CdcAcmClass, State},
        hid::{self, RequestHandler},
    },
    driver::EndpointError,
};
//#[cfg(not(feature = "defmt"))]
//use panic_halt as _;
#[cfg(feature = "defmt")]
use defmt_rtt as _;
use embedded_hal::i2c::Operation;
use sync_unsafe_cell::SyncUnsafeCell;
use usbd_hid::descriptor::gen_hid_descriptor;

use embassy_executor::Spawner;
use embassy_futures::join::{join, join_array, join3, join4, join5};
use embassy_stm32::{
    adc::{self, Adc, AdcChannel, AnyAdcChannel},
    bind_interrupts, dma,
    gpio::{Input as GpioInput, Level, Output, Speed},
    i2c::{self, I2c, Master},
    mode::Async,
    peripherals::{self, ADC1, DMA1_CH4, PA8, PB8, USB},
    rcc::mux::ClockMux,
    time::Hertz,
    usb::{self, Driver, Instance},
};
use embassy_time::{Duration, Instant, Ticker, Timer};
//use fmt::info;
use embedded_hal_async::i2c::I2c as _;

use crate::{
    alloc::BumpAllocator,
    log::{info, log_receiver},
    trace::{reset_profile, set_task_name, take_profile},
};

bind_interrupts!(struct Irqs {
    USB => usb::InterruptHandler<peripherals::USB>;
    ADC1_COMP => adc::InterruptHandler<peripherals::ADC1>;
    I2C2 => i2c::EventInterruptHandler<peripherals::I2C2>, i2c::ErrorInterruptHandler<peripherals::I2C2>;
    DMA1_CHANNEL4_5_6_7 => dma::InterruptHandler<peripherals::DMA1_CH4>, dma::InterruptHandler<peripherals::DMA1_CH5>;
});

static PANIC_COUNT: AtomicUsize = AtomicUsize::new(0);

fn set_panic_count(cnt: usize) {
    PANIC_COUNT.store(cnt, core::sync::atomic::Ordering::SeqCst);
}

#[panic_handler]
fn panic(info: &PanicInfo) -> ! {
    // Safety: We've panicked
    let pb8 = unsafe { PB8::steal() };
    let mut led = Output::new(pb8, Level::Low, Speed::Low);

    loop {
        let count = PANIC_COUNT.load(core::sync::atomic::Ordering::SeqCst);
        for _ in 0..count {
            led.set_high();
            for _ in 0..2_000_000 {
                black_box(());
            }
            led.set_low();
            for _ in 0..2_000_000 {
                black_box(());
            }
        }

        led.set_low();
        for _ in 0..10_000_000 {
            black_box(());
        }
    }
}

struct Disconnected {}

impl From<EndpointError> for Disconnected {
    fn from(val: EndpointError) -> Self {
        match val {
            EndpointError::BufferOverflow => panic!("Buffer overflow"),
            EndpointError::Disabled => Disconnected {},
        }
    }
}

static ALLOCATOR: BumpAllocator<4096> = BumpAllocator::new();

/*struct PoolAllocator<M, T, const N: usize> {
    pool: [SyncUnsafeCell<T>; N],
    free: SyncUnsafeCell<[u8; N]>,
    mutex: M,
}

struct PoolAllocatorGuard<'a, M: RawMutex, T, const N: usize> {
    pool: &'a PoolAllocator<M, T, N>,
    //target: &'a mut T,
    index: usize,
}

impl<'a, M: RawMutex, T, const N: usize> Deref for PoolAllocatorGuard<'a, M, T, N> {
    type Target = T;

    fn deref(&self) -> &Self::Target {
        unsafe { &*(self.pool.pool[self.index].get() as *const T) }
    }
}

impl<'a, M: RawMutex, T, const N: usize> DerefMut for PoolAllocatorGuard<'a, M, T, N> {
    fn deref_mut(&mut self) -> &mut Self::Target {
        unsafe { &mut *(self.pool.pool[self.index].get()) }
    }
}

impl<'a, M: RawMutex, T, const N: usize> Drop for PoolAllocatorGuard<'a, M, T, N> {
    fn drop(&mut self) {
        self.pool.mutex.lock(|| unsafe {
            let free = unsafe { &mut *self.pool.free.get() };
            free[self.index] = 1;
        });
    }
}

impl<M: RawMutex, T: Copy, const N: usize> PoolAllocator<M, T, N> {
    const fn new(init_array: [SyncUnsafeCell<T>; N]) -> Self {
        Self {
            pool: init_array,
            free: SyncUnsafeCell::new([1; N]),
            mutex: M::INIT,
        }
    }
}

impl<M: RawMutex, T, const N: usize> PoolAllocator<M, T, N> {
    fn allocate<'a>(&'a self) -> Option<PoolAllocatorGuard<'a, M, T, N>> {
        self.mutex.lock(|| {
            let free = unsafe { &mut *self.free.get() };
            for idx in 0..N {
                if free[idx] == 1 {
                    free[idx] = 0;
                    return Some(PoolAllocatorGuard {
                        pool: self, //unsafe { &mut *(((self) as *const Self) as *mut Self) },
                        index: idx,
                    });
                }
            }
            None
        })
    }
}

// TODO: Can we get rid of Copy?
#[derive(Clone, Copy)]
struct PendingMessage {
    message: [u8; 256],
    len: usize,
}

impl PendingMessage {
    const fn new() -> Self {
        Self {
            message: [0; 256],
            len: 0,
        }
    }

    fn reset(&mut self) {
        self.len = 0;
    }

    fn push_char(&mut self, c: u8) {
        if self.len < self.message.len() {
            self.message[self.len] = c;
            self.len += 1;
        }
    }
}

impl core::fmt::Write for PendingMessage {
    fn write_str(&mut self, s: &str) -> core::fmt::Result {
        for c in s.chars() {
            if c == '\n' {
                self.push_char(b'\r');
                self.push_char(b'\n');
            } else if let Some(ascii) = c.as_ascii() {
                self.push_char(ascii.to_u8());
            } else {
                self.push_char(b'?');
            }
        }
        core::fmt::Result::Ok(())
    }
}

static UART_MESSAGE_POOL: PoolAllocator<ThreadModeRawMutex, PendingMessage, 3> =
    PoolAllocator::new([const { SyncUnsafeCell::new(PendingMessage::new()) }; 3]);

/*static UART_SENDER: OnceLock<
    Sender<ThreadModeRawMutex, PoolAllocatorGuard<'static, PendingMessage>, 4>,
> = OnceLock::new();*/

static UART_CHANNEL: Channel<
    ThreadModeRawMutex,
    PoolAllocatorGuard<'static, ThreadModeRawMutex, PendingMessage, 3>,
    3,
> = Channel::<ThreadModeRawMutex, _, _>::new();

macro_rules! info {
    ($s:literal $(, $x:expr)* $(,)?) => {
        {
            let args = core::format_args!($s $(, $x)*);

            if let Some(mut message) = UART_MESSAGE_POOL.allocate() {
                message.reset();
                core::fmt::write(&mut *message, args);
                message.write_str("\n");
                /*message.len = 6;
                message.message[0] = b'h';
                message.message[1] = b'e';
                message.message[2] = b'l';
                message.message[3] = b'l';
                message.message[4] = b'o';
                message.message[5] = b'\n';*/

                UART_CHANNEL.sender().send(message).await;
            }

            /*if let Some(message) = $out.try_send() {
                message.len = 6;
                message.message[0] = b'h';
            }*/

            /*#[cfg(feature = "defmt")]
            ::defmt::info!($s $(, $x)*);
            #[cfg(not(feature="defmt"))]
            let _ = ($( & $x ),*);*/
        }
    };
}*/

/*async fn echo<'d, T: Instance + 'd>(
    class: &mut CdcAcmClass<'d, Driver<'d, T>>,
) -> Result<(), Disconnected> {
    let mut buf = [0; 64];
    loop {
        let n = class.read_packet(&mut buf).await?;
        let data = &buf[..n];
        info!("data: {:x}", data);

        let mut buf = [0; 256];
        let mut offset = 0;
        for c in b"Hello from USB land! You said: '" {
            buf[offset] = *c;
            offset += 1;
        }
        for c in data.iter() {
            buf[offset] = *c;
            offset += 1;
        }
        for c in b"'\r\n" {
            buf[offset] = *c;
            offset += 1;
        }
        let buf = &buf[0..offset];
        class.write_packet(buf).await?;
    }
}*/

struct Input {
    constant: bool,
    variable: bool,
    relative: bool,
    wrap: bool,
    non_linear: bool,
    no_preferred_state: bool,
    null_state: bool,
    buffered_bytes: bool,
}

impl Input {
    const fn make_payload(&self) -> ShortDataPayload {
        let mut res = 0;
        if self.constant {
            res |= 1 << 0;
        }
        if self.variable {
            res |= 1 << 1;
        }
        if self.relative {
            res |= 1 << 2;
        }
        if self.wrap {
            res |= 1 << 3;
        }
        if self.non_linear {
            res |= 1 << 4;
        }
        if self.no_preferred_state {
            res |= 1 << 5;
        }
        if self.null_state {
            res |= 1 << 6;
        }
        if self.buffered_bytes {
            res |= 1 << 8;
        }
        ShortDataPayload::U32(res)
    }
}

enum Collection {
    Physical,
    Application,
    Logical,
    Report,
    NamedArray,
    UsageSwitch,
    UsageModifier,
}

impl Collection {
    const fn tag(&self) -> u8 {
        match self {
            Self::Physical => 0,
            Self::Application => 1,
            Self::Logical => 2,
            Self::Report => 3,
            Self::NamedArray => 4,
            Self::UsageSwitch => 5,
            Self::UsageModifier => 6,
        }
    }
}

enum Item {
    // Main items
    Input(Input),
    Output,
    Feature,
    Collection(Collection),
    EndCollection,

    // Global items
    UsagePage,
    LogicalMinimum(u16),
    LogicalMaximum(u16),
    PhysicalMinimum,
    PhysicalMaximum,
    UnitExponent,
    Unit,
    ReportSize(u8),
    ReportId,
    ReportCount(u8),
    Push,
    Pop,

    // Local items
    Usage,
    UsageMinimum,
    UsageMaximum,
    DesignatorIndex,
    DesignatorMinimum,
    DesignatorMaximum,
    StringIndex,
    StringMinimum,
    StringMaximum,
    Delimiter,
}

enum ShortDataPayload {
    None,
    U8(u8),
    U16(u16),
    U32(u32),
}

impl ShortDataPayload {
    const fn len(&self) -> u8 {
        match self {
            Self::None => 0,
            Self::U8(_) => 1,
            Self::U16(_) => 2,
            Self::U32(_) => 3,
        }
    }
}

impl Item {
    const fn btype(&self) -> u8 {
        match self {
            Self::Input(_)
            | Self::Output
            | Self::Feature
            | Self::Collection(_)
            | Self::EndCollection => 0,
            Self::UsagePage
            | Self::LogicalMaximum(_)
            | Self::LogicalMinimum(_)
            | Self::PhysicalMinimum
            | Self::PhysicalMaximum
            | Self::UnitExponent
            | Self::Unit
            | Self::ReportSize(_)
            | Self::ReportId
            | Self::ReportCount(_)
            | Self::Push
            | Self::Pop => 1,
            Self::Usage
            | Self::UsageMinimum
            | Self::UsageMaximum
            | Self::DesignatorIndex
            | Self::DesignatorMinimum
            | Self::DesignatorMaximum
            | Self::StringIndex
            | Self::StringMinimum
            | Self::StringMaximum
            | Self::Delimiter => 2,
        }
    }

    const fn btag(&self) -> u8 {
        match self {
            Self::Input(_) => 8,
            Self::Output => 9,
            Self::Feature => 0b1011,
            Self::Collection(_) => 0b1010,
            Self::EndCollection => 0b1100,

            Self::UsagePage => 0,
            Self::LogicalMinimum(_) => 1,
            Self::LogicalMaximum(_) => 2,
            Self::PhysicalMinimum => 3,
            Self::PhysicalMaximum => 4,
            Self::UnitExponent => 5,
            Self::Unit => 6,
            Self::ReportSize(_) => 7,
            Self::ReportId => 8,
            Self::ReportCount(_) => 9,
            Self::Push => 0b1010,
            Self::Pop => 0b1011,

            Self::Usage => 0,
            Self::UsageMinimum => 1,
            Self::UsageMaximum => 2,
            Self::DesignatorIndex => 3,
            Self::DesignatorMinimum => 4,
            Self::DesignatorMaximum => 5,
            Self::StringIndex => 7,
            Self::StringMinimum => 8,
            Self::StringMaximum => 9,
            Self::Delimiter => 10,
        }
    }

    const fn serialize_data(&self) -> ShortDataPayload {
        match self {
            Self::Input(input) => input.make_payload(),
            Self::Collection(collection) => ShortDataPayload::U8(collection.tag()),
            Self::EndCollection => ShortDataPayload::None,
            Self::LogicalMinimum(minimum) => ShortDataPayload::U16(*minimum),
            Self::LogicalMaximum(maximum) => ShortDataPayload::U16(*maximum),
            Self::ReportSize(v) | Self::ReportCount(v) => ShortDataPayload::U8(*v),
            _ => todo!(),
        }
    }
}

struct ReportDescriptorWriter<'a> {
    buf: &'a mut [u8],
    offset: usize,
}
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
async fn main(spawner: Spawner) {
    set_panic_count(1);

    let mut config = embassy_stm32::Config::default();
    {
        use embassy_stm32::rcc::*;

        config.rcc.hsi48 = Some(Hsi48Config {
            sync_from_usb: true,
        });
        config.rcc.sys = Sysclk::HSI48;
        config.rcc.ahb_pre = AHBPrescaler::DIV1;
        config.rcc.apb1_pre = APBPrescaler::DIV1;
    }

    let p = embassy_stm32::init(config);
    let mut led = Output::new(p.PB8, Level::Low, Speed::Low);

    let mut int0 = GpioInput::new(p.PB3, embassy_stm32::gpio::Pull::Up);
    let mut int1 = GpioInput::new(p.PB4, embassy_stm32::gpio::Pull::Up);
    let mut int2 = GpioInput::new(p.PB5, embassy_stm32::gpio::Pull::Up);
    let mut int3 = GpioInput::new(p.PB12, embassy_stm32::gpio::Pull::Up);

    let mut adc = Adc::new(p.ADC1, Irqs);
    let vref = adc.enable_vref();

    let mut i2c_config = embassy_stm32::i2c::Config::default(); /*{
    frequency: Hertz::khz(400),
    gpio_speed: Speed::VeryHigh,
    sda_pullup: true,
    scl_pullup: true,
    timeout: Duration::from_millis(500),
    };*/
    i2c_config.frequency = Hertz::khz(400);
    i2c_config.timeout = Duration::from_millis(50);
    let mut i2c = I2c::new(
        p.I2C2, p.PB10, p.PB11, p.DMA1_CH4, p.DMA1_CH5, Irqs, i2c_config,
    );

    let driver = Driver::new(p.USB, Irqs, p.PA12, p.PA11);

    // Note: This VID/PID is a reserved testing PID
    let mut config = embassy_usb::Config::new(0x1209, 0x000d);
    config.manufacturer = Some("Pillow Computing Consortium");
    config.product = Some("Flightpanel");
    config.serial_number = Some(embassy_stm32::uid::uid_hex());
    config.composite_with_iads = ENABLE_SERIAL;
    if !ENABLE_SERIAL {
        config.device_class = 3; // USB HID
        config.device_sub_class = 0; // No subclass (i.e. not boot)
        config.device_protocol = 0; // No protocol (i.e. neither mouse nor keyboard)
    }

    // Create embassy-usb DeviceBuilder using the driver and config.
    // It needs some buffers for building the descriptors.
    let mut config_descriptor = ALLOCATOR.alloc([0; 256]);
    let mut bos_descriptor = ALLOCATOR.alloc([0; 256]);
    let mut control_buf = ALLOCATOR.alloc([0; 64]);

    let mut state = ALLOCATOR.alloc(State::new());

    let mut hid_state = ALLOCATOR.alloc(hid::State::new());
    let mut hid_report_descriptor = [0; 512];

    let mut builder = Builder::new(
        driver,
        config,
        config_descriptor,
        bos_descriptor,
        &mut [], // no msos descriptors
        control_buf,
    );

    // Create classes on the builder.
    let mut class = if ENABLE_SERIAL {
        Some(CdcAcmClass::new(&mut builder, state, 64))
    } else {
        None
    };

    //let hid_report_descriptor_size = build_report_descriptor(&mut hid_report_descriptor);
    let mut hid_class = hid::Config {
        report_descriptor: JoyReport::desc(),
        request_handler: None,
        poll_ms: 10,
        max_packet_size: 64,
        hid_boot_protocol: hid::HidBootProtocol::None,
        hid_subclass: hid::HidSubclass::No,
    };
    let rw = hid::HidReaderWriter::<_, 1, 16>::new(&mut builder, hid_state, hid_class);

    let mut request_handler = JoyRequestHandler {};

    // Build the builder.
    let mut usb = builder.build();

    // Run the USB device.
    //let usb_fut = usb.run();

    let (joy_reader, mut joy_writer) = rw.split();

    /*let mut uart_buf = [
        PendingMessage::new(),
        PendingMessage::new(),
        PendingMessage::new(),
    ];*/
    //let mut uart_channel = Channel::<ThreadModeRawMutex, _, _>::new();
    //let (mut log_tx, mut log_rx) = uart_channel.split();
    //UART_SENDER.init(uart_channel.sender());
    //let log_rx = UART_CHANNEL.receiver();
    //let log_rx = log_receiver();

    //UART_SENDER.init(uart_tx);

    // Do stuff with the class!
    /*let echo_fut = async {
        //let (tx, rx) = class.split();

        loop {
            class.wait_connection().await;
            info!("Connected");
            let _ = echo(&mut class).await;
            info!("Disconnected");
        }
    };*/

    /*let uart_send_fut = async {
        uart_tx.wait_connection().await;
        while let message = log_rx.receive().await {
            uart_tx.wait_connection().await;
            for i in 0..message.len {
                uart_tx.write_packet(&[message.message[i]]).await;
            }
            //log_rx.receive_done();
        }
    };*/

    I2C_TASK_CHANNEL.send(I2cTask::Poll(0)).await;

    if let Some(class) = class {
        let (mut uart_tx, mut uart_rx) = class.split();

        let task = crate::log::log_task(uart_tx).unwrap();
        set_task_name(task.id(), "log");
        spawner.spawn(task);

        let task = cli_task(uart_rx).unwrap();
        set_task_name(task.id(), "cli");
        spawner.spawn(task);
    }

    let task = led_task(led).unwrap();
    set_task_name(task.id(), "led");
    spawner.spawn(task);

    let task = usb_task(usb).unwrap();
    set_task_name(task.id(), "usb");
    spawner.spawn(task);

    let task = joystick_update_task(joy_writer).unwrap();
    set_task_name(task.id(), "joystick_update");
    spawner.spawn(task);

    let task = joystick_input_task(joy_reader, request_handler).unwrap();
    set_task_name(task.id(), "joystick_input");
    spawner.spawn(task);

    let task = adc_task(
        adc,
        [
            p.PA0.degrade_adc(),
            p.PA1.degrade_adc(),
            p.PA2.degrade_adc(),
            p.PA3.degrade_adc(),
            p.PA4.degrade_adc(),
            p.PA5.degrade_adc(),
            p.PA6.degrade_adc(),
            p.PA7.degrade_adc(),
        ],
        vref.degrade_adc(),
    )
    .unwrap();
    set_task_name(task.id(), "adc");
    spawner.spawn(task);

    set_panic_count(2);

    //static I2C_BUS: StaticCell<Mutex<NoopRawMutex, _>> = StaticCell::new();
    let i2c_bus = ALLOCATOR.alloc(Mutex::new(i2c));
    //let i2c_bus = Mutex::new(i2c);
    //let i2c_bus = I2C_BUS.init(i2c_bus);
    let i2c1 = I2cDevice::new(i2c_bus);
    //let i2c2 = I2cDevice::new(i2c_bus);

    //set_panic_count(3);

    let task = interrupt_i2c_task(i2c1, [int2, int0, int3, int1]).unwrap();
    set_task_name(task.id(), "i2c");
    spawner.spawn(task);

    /*let task = i2c_task(i2c1).unwrap();
    set_task_name(task.id(), "i2c1");
    spawner.spawn(task);

    set_panic_count(4);

    let task = i2c_task(i2c2).unwrap();
    set_task_name(task.id(), "i2c2");
    spawner.spawn(task);*/

    /*let uart_recv_fut = async {
        loop {
            uart_rx.wait_connection().await;
            let mut packet = [0; 128];
            uart_rx.read_packet(&mut packet).await;
        }
    };*/

    /*let led_fut = {
        //let log_tx = log_tx.clone();
        async move {
            loop {
                info!("Hello, World!");
                led.set_high();
                Timer::after(Duration::from_millis(500)).await;
                led.set_low();
                Timer::after(Duration::from_millis(500)).await;
            }
        }
    };*/

    /*let joy_fut = async {
        loop {
            //joy_writer.write(&[0]).await;
            match joy_writer.write_serialize(&JoyReport { x: 1, y: 0 }).await {
                Ok(_) => {}
                Err(e) => {
                    info!("foo");
                }
            }
            Timer::after(Duration::from_millis(500)).await;
            joy_writer.write_serialize(&JoyReport { x: 0, y: 1 }).await;
            Timer::after(Duration::from_millis(500)).await;
        }
    };

    let joy_out_fut = async {
        joy_reader.run(false, &mut request_handler).await;
    };*/

    // Run everything concurrently.
    // If we had made everything `'static` above instead, we could do this using separate tasks instead.
    //join2(joy_fut, joy_out_fut).await;

    // All the tasks are set up, so just hang out
    /*loop {
        Timer::after(Duration::from_millis(1000)).await;
    }*/

    /*loop {
        info!("Hello, World!");
        led.set_high();
        Timer::after(Duration::from_millis(500)).await;
        led.set_low();
        Timer::after(Duration::from_millis(500)).await;
    }*/

    set_panic_count(5);
}

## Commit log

2026-01-10 Initial commit, v1.0
    [bom.csv, buttons.kicad_sch, designators.csv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]
2026-01-11 Various tweaks
    [flightpanel.FCStd]
2026-03-10 Working firmware, update HW to fix collisions
    [flightpanel.FCStd]
2026-03-11 Minor changes
    [flightpanel-PartStructureBase.stl, flightpanel-PartStructureTop.stl, flightpanel.FCStd]
